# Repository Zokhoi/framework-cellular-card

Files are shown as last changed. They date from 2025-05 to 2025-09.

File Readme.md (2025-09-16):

## Framework Cellular Expansion Card

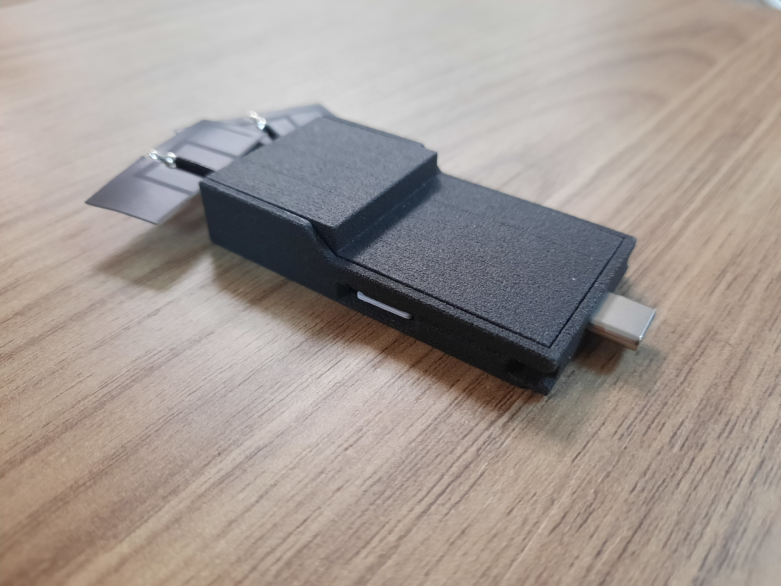
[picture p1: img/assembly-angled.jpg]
assembly-angled


Compatible with Quectel cellular modules with same pinout as BG96.

This PCB design has been tested with EG912U-GL and EG95-EX modules. Other modules with compatible pinout will need different component values in various positions, consult the relevant hardware design information for details.

This PCB design is in alpha state, therefore gerber will not be provided and you should only proceed ordering at your own risk.

This PCB design does not incorporate built in antennas, and instead includes MHF-1 connectors for LTE main, diversity and GNSS. Thus you should pair your own 50 ohms impedance LTE antenna.

The PCB is 15mm longer than a regular expansion card PCB, a preliminary case design is provided.

### Board specifications

Size 26mm x 45mm, thickness 0.8mm, 4 layers, copper thickness 1oz 0.5oz 0.5oz 1oz, impedance controlled board with 0.2mm prepreg

### Compatible modem series comparison

| Modem series | Cellular standards | Downlink speed | Uplink speed | Cost |
|---|---|---|---|---|
| EG95 | 4G, 3G, 2G | 150 Mb/s |  50 Mb/s | \$\$ |
| EG91 | 4G, 2G |  10 Mb/s | 5 Mb/s | \$ |
| BG96 | Cat-M, Cat-NB1 | 375 Kb/s | 375 Kb/s | \$\$ |

### License
This hardware design is licensed under [CERN-OHL-W V2 or later](License.txt).

### Board preview
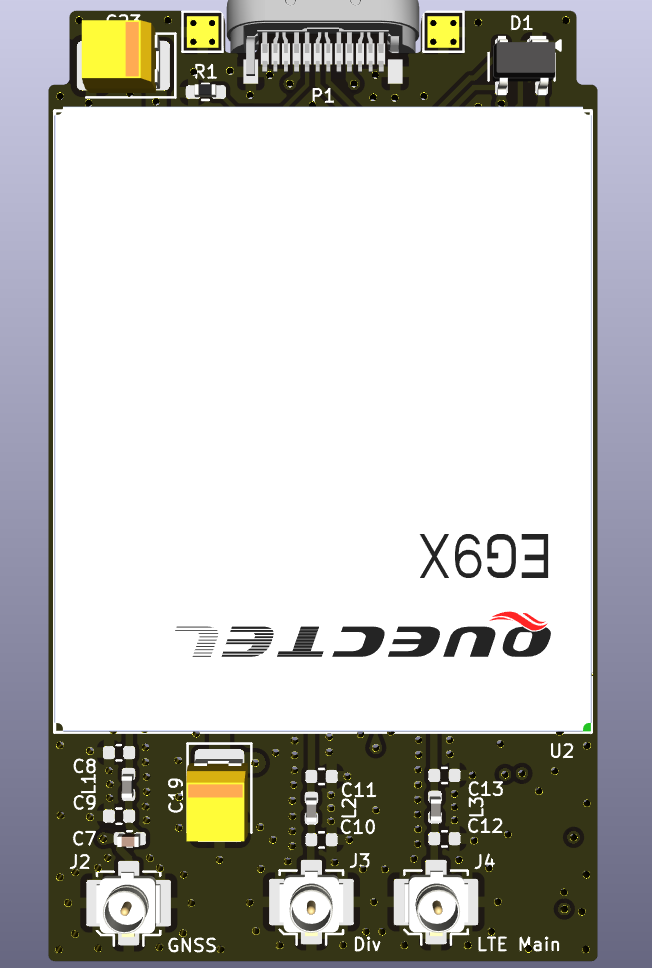
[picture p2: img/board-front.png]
front


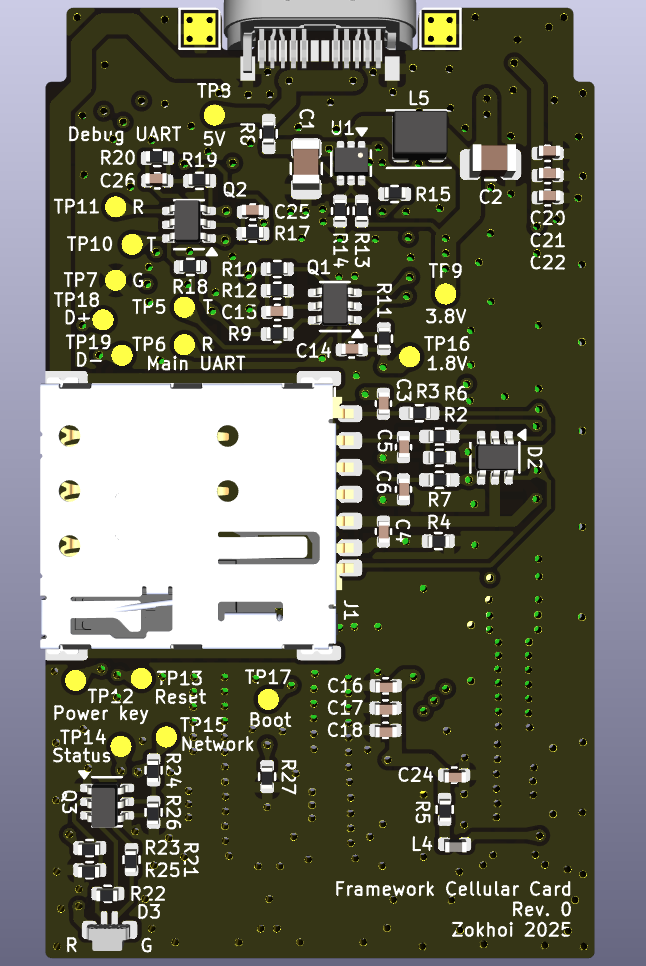
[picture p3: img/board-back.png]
back


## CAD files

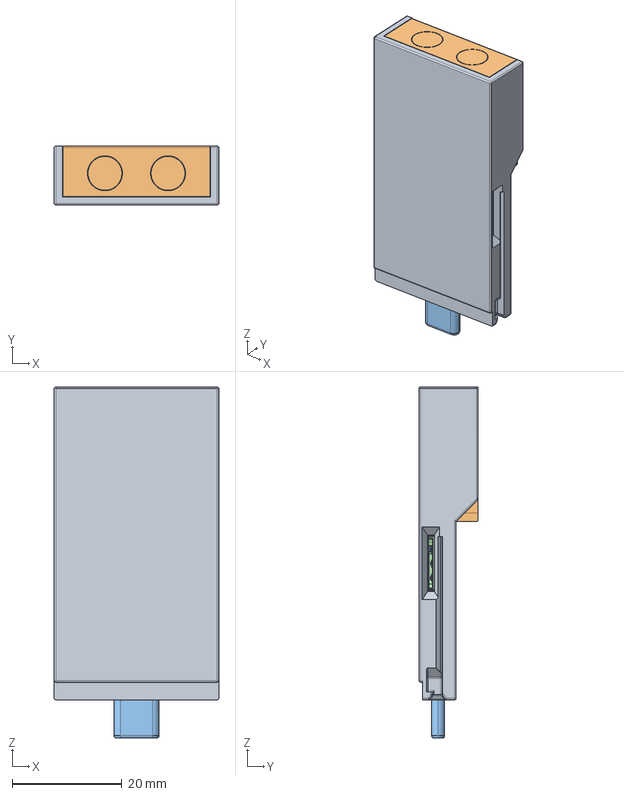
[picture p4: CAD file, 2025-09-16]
case/usb-lte-case.FCStd
30.0 x 10.8 x 64.0 mm
Bottom shell
Top shell
C_0402_1005Metric
C_0402_1005Metric002
U.FL_Hirose_U.FL-R-SMT-1_Vertical
C_0402_1005Metric004
C_0402_1005Metric006
C_0402_1005Metric008
C_0402_1005Metric010
C_0402_1005Metric012
L_0402_1005Metric
L_0402_1005Metric002
U.FL_Hirose_U.FL-R-SMT-1_Vertical002
L_0402_1005Metric004
R_0402_1005Metric
CP_EIA_3528_21_Kemet_B
CP_EIA_3528_21_Kemet_B001
SOT_143
U.FL_Hirose_U.FL-R-SMT-1_Vertical004
EG91
EG092
EG093
EG094
EG095
EG096
EG097
EG098
EG099
EG100
EG101
EG102
EG103
EG104
EG105
EG106
EG107
EG108
EG109
EG110
EG111
EG112
EG113
EG114
EG115
EG116
EG117
EG118
EG119
EG120
EG121
EG122
EG123
EG124
EG125
EG126
EG127
EG128
EG129
EG130
EG131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

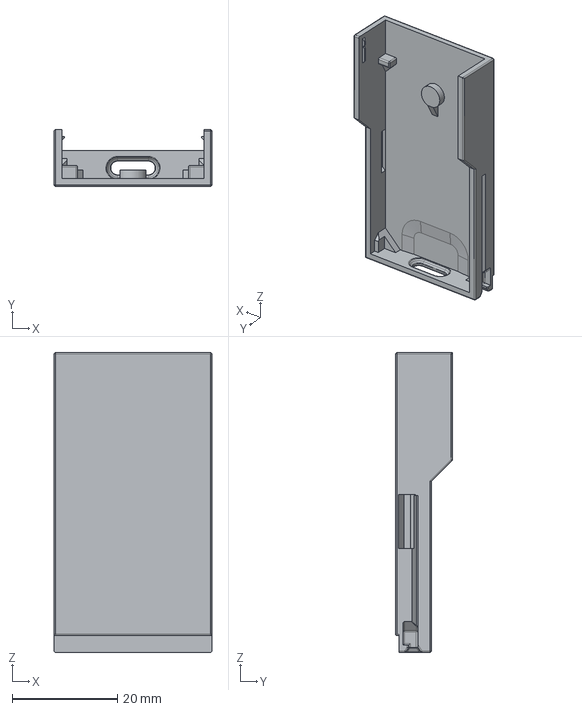
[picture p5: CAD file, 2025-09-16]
case/v1/usb-lte-case-Bottom shell.step
30.0 x 10.8 x 57.0 mm

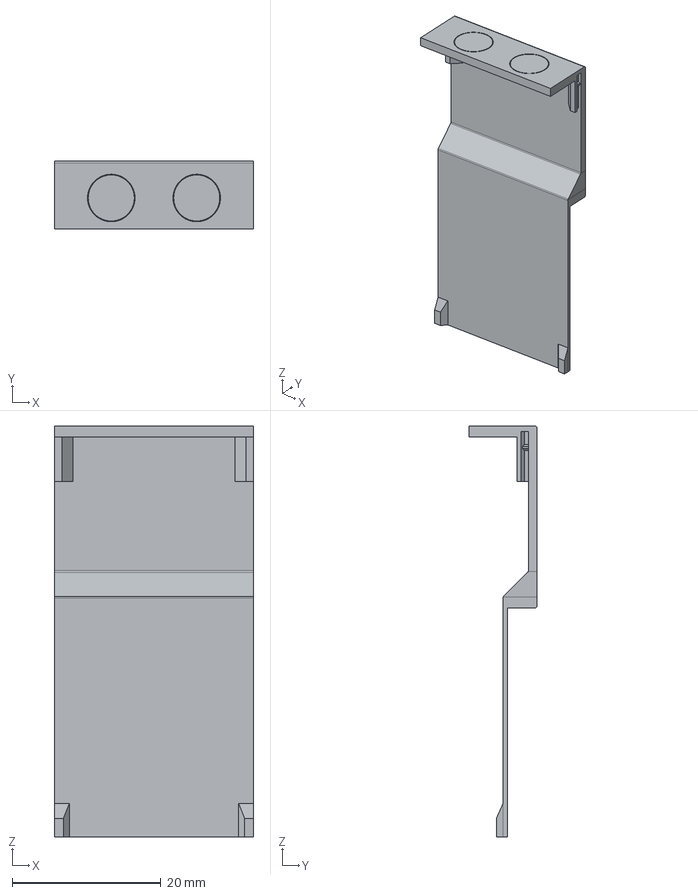
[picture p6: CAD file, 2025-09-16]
case/v1/usb-lte-case-Top shell.step
26.8 x 9.20 x 55.3 mm

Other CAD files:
case/v1/usb-lte-case-Bottom shell.3mf
case/v1/usb-lte-case-Top shell.3mf

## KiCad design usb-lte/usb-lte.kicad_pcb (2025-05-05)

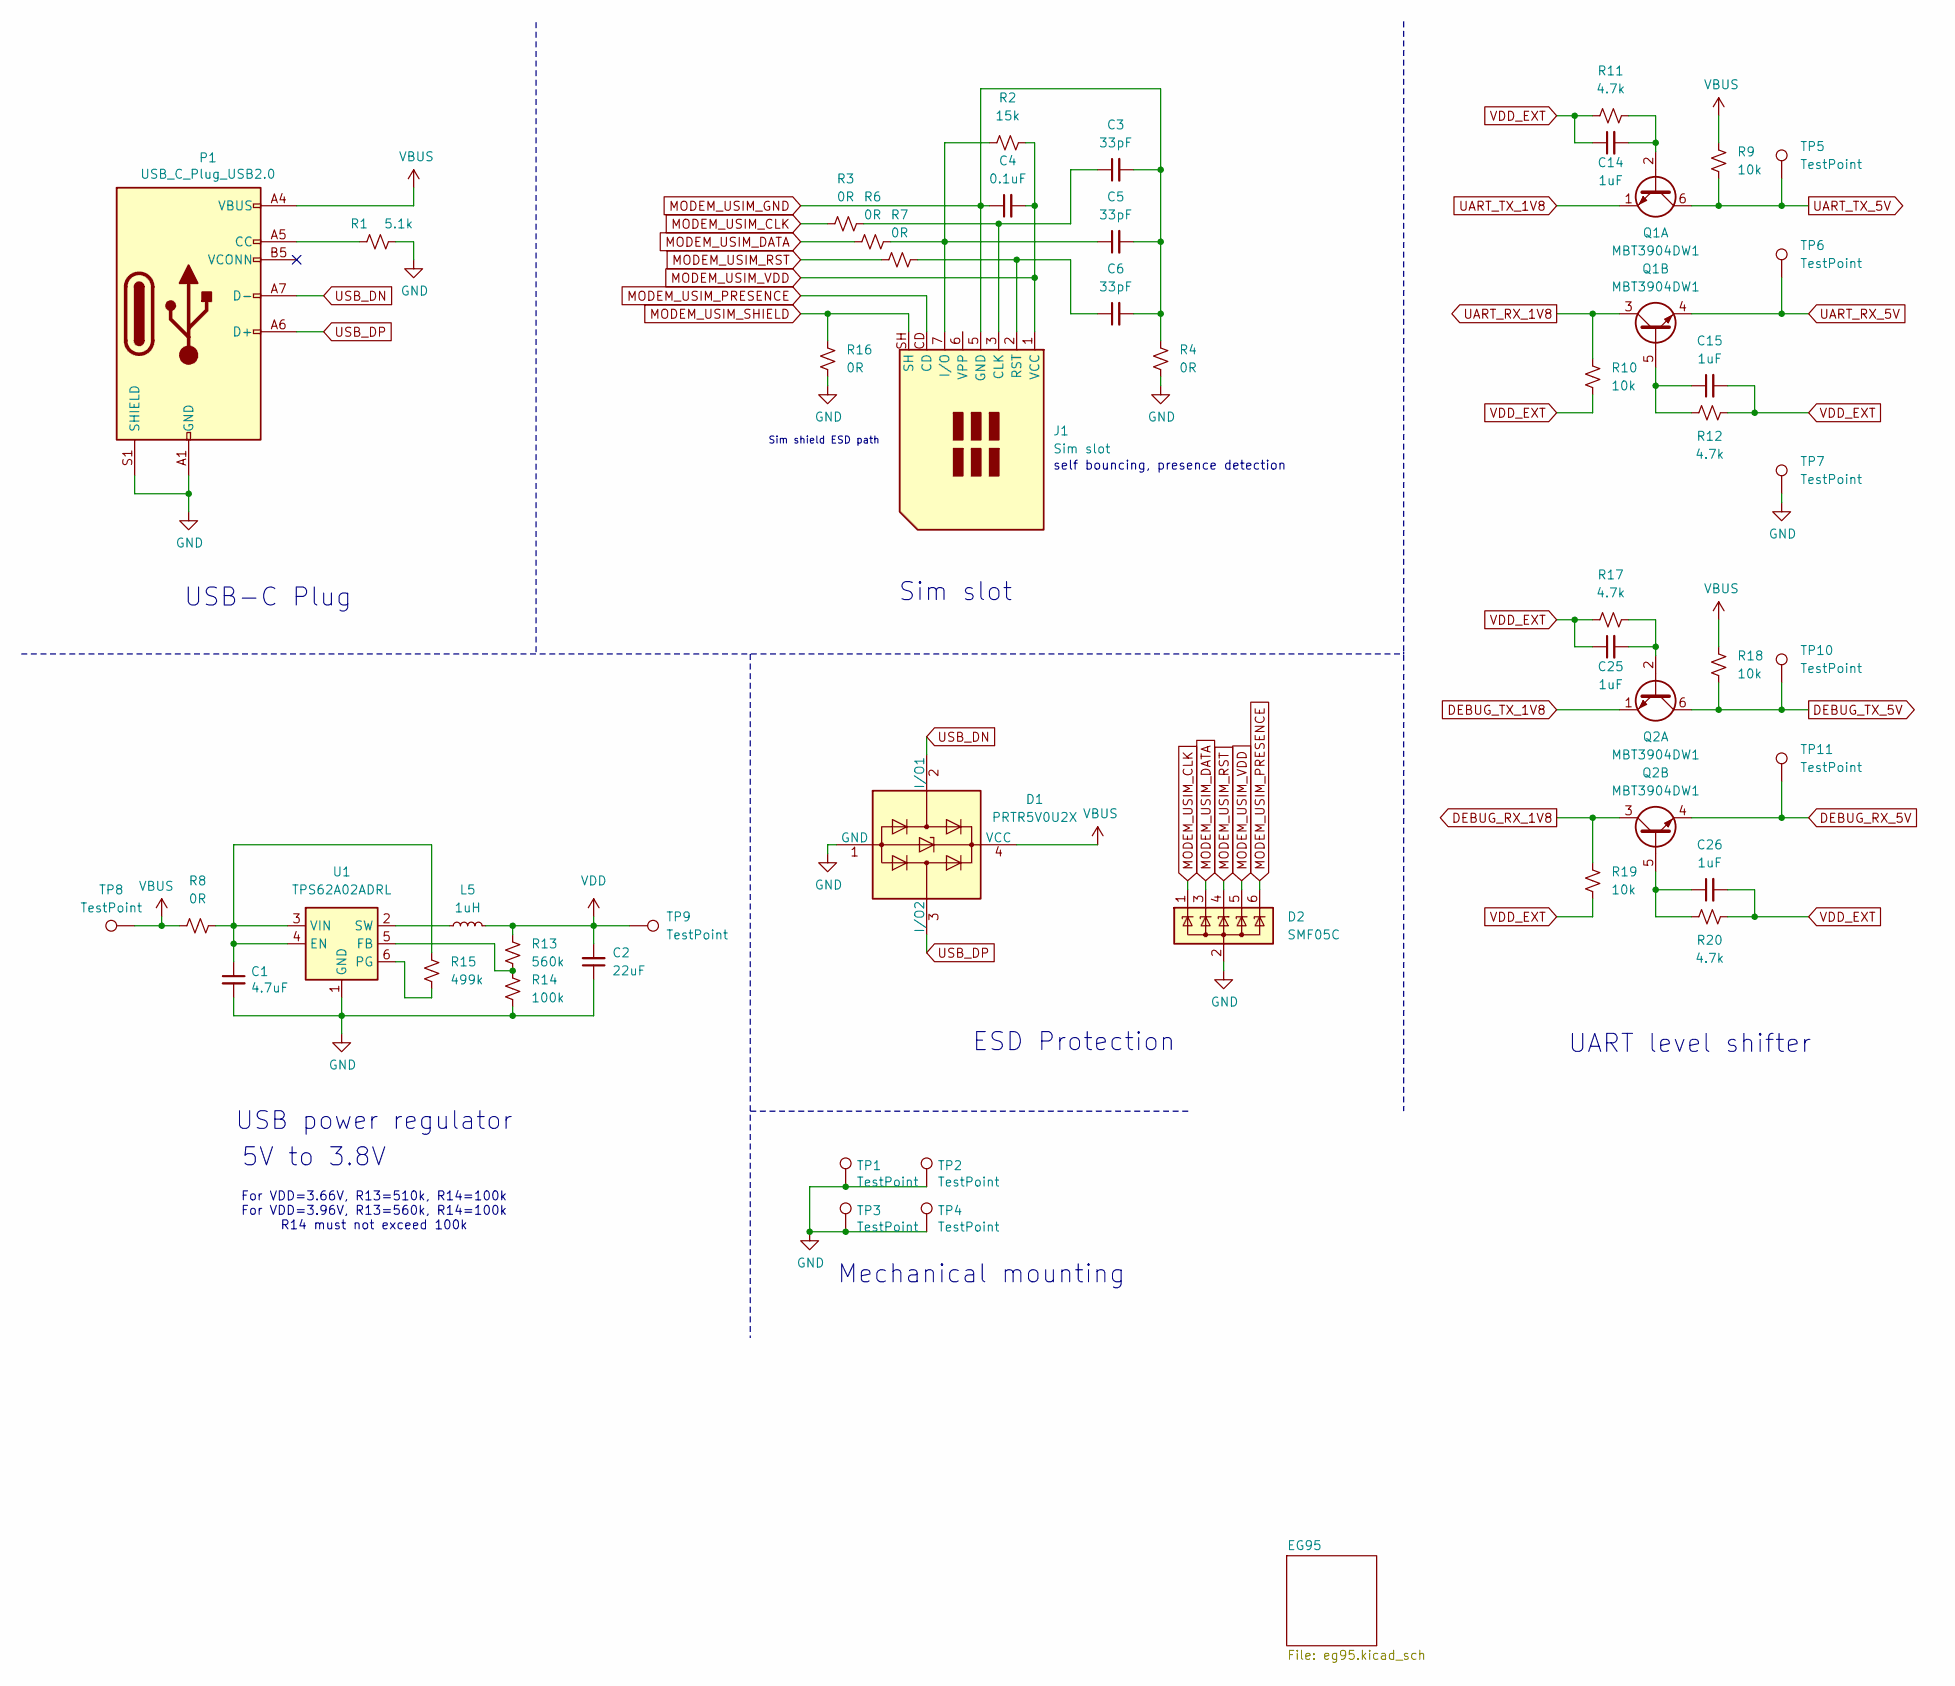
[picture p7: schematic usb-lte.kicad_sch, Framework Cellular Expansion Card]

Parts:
C1: 4.7uF; C_0805_2012Metric
C2: 22uF; C_0805_2012Metric
C3, C5, C6: 33pF; C_0402_1005Metric
C4: 0.1uF; C_0402_1005Metric
C14, C15, C25, C26: 1uF; C_0402_1005Metric
D1: PRTR5V0U2X; SOT-143
D2: SMF05C; SOT-363_SC-70-6
J1: Sim slot; SIM_Card_Self_Bounce_Detection
L5: 1uH; L_APV_ANR252012
P1: USB_C_Plug_USB2.0; USB_C_Plug_Molex_105444
Q1, Q2: MBT3904DW1; SOT-363_SC-70-6
R1: 5.1k; R_0402_1005Metric_Pad0.72x0.64mm_HandSolder
R2: 15k; R_0402_1005Metric
R3, R6, R7, R8: 0R; R_0402_1005Metric_Pad0.72x0.64mm_HandSolder
R4: 0R; R_0402_1005Metric
R9, R10, R18, R19: 10k; R_0402_1005Metric
R11, R12, R17, R20: 4.7k; R_0402_1005Metric
R13: 560k; R_0402_1005Metric
R14: 100k; R_0402_1005Metric
R15: 499k; R_0402_1005Metric
R16: 0R; ESD shunt
TP1, TP2, TP3, TP4: TestPoint; TestPoint_Pad_1.5x1.5mm
TP5, TP6, TP7, TP8, TP9, TP10, TP11: TestPoint; TestPoint_Pad_1mm
U1: TPS62A02ADRL; SOT-563

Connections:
DEBUG_RX_1V8: Q2.3 (C2), R19.1; also elsewhere on the board
DEBUG_RX_5V: Q2.4 (E2), TP11.1
DEBUG_TX_1V8: Q2.1 (E1); also elsewhere on the board
DEBUG_TX_5V: Q2.6 (C1), R18.2, TP10.1
GND: C1.2, C2.1, D1.1 (GND), D2.2 (A), P1.A1 (GND), P1.A12 (GND), P1.B1 (GND), P1.B12 (GND), P1.S1 (SHIELD), R1.2, R4.2, R14.2, R16.2, TP1.1, TP2.1, TP3.1, TP4.1, TP7.1, U1.1 (GND); also elsewhere on the board
MODEM_USIM_CLK: D2.1 (K), R3.1; also elsewhere on the board
MODEM_USIM_DATA: D2.3 (K), R6.1; also elsewhere on the board
MODEM_USIM_GND: C3.2, C4.1, C5.2, C6.2, J1.5 (GND), R4.1; also elsewhere on the board
MODEM_USIM_PRESENCE: D2.6 (K), J1.CD; also elsewhere on the board
MODEM_USIM_RST: D2.4 (K), R7.1; also elsewhere on the board
MODEM_USIM_SHIELD: J1.SH, R16.1
MODEM_USIM_VDD: C4.2, D2.5 (K), J1.1 (VCC), R2.2; also elsewhere on the board
unnamed: C3.1, J1.3 (CLK), R3.2
unnamed: C5.1, J1.7 (I/O), R2.1, R6.2
unnamed: C6.1, J1.2 (RST), R7.2
unnamed: P1.A5 (CC), R1.1
unnamed: C14.2, Q1.2 (B1), R11.2
unnamed: C15.1, Q1.5 (B2), R12.1
unnamed: C25.2, Q2.2 (B1), R17.2
unnamed: C26.1, Q2.5 (B2), R20.1
unnamed: C1.1, R8.2, R15.2, U1.3 (VIN), U1.4 (EN)
unnamed: R13.2, R14.1, U1.5 (FB)
unnamed: R15.1, U1.6 (PG)
unnamed: L5.1, U1.2 (SW)
UART_RX_1V8: Q1.3 (C2), R10.1; also elsewhere on the board
UART_RX_5V: Q1.4 (E2), TP6.1
UART_TX_1V8: Q1.1 (E1); also elsewhere on the board
UART_TX_5V: Q1.6 (C1), R9.2, TP5.1
USB_DN: D1.2 (I/O1), P1.A7 (D-); also elsewhere on the board
USB_DP: D1.3 (I/O2), P1.A6 (D+); also elsewhere on the board
VBUS: D1.4 (VCC), P1.A4 (VBUS), P1.A9 (VBUS), P1.B4 (VBUS), P1.B9 (VBUS), R8.1, R9.1, R18.1, TP8.1; also elsewhere on the board
VDD: C2.2, L5.2, R13.1, TP9.1; also elsewhere on the board
VDD_EXT: C14.1, C15.2, C25.1, C26.2, R10.2, R11.1, R12.2, R17.1, R19.2, R20.2; also elsewhere on the board

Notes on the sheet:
Sim slot
USB power regulator
For VDD=3.66V, R13=510k, R14=100k For VDD=3.96V, R13=560k, R14=100k R14 must not exceed 100k
Mechanical mounting
self bouncing, presence detection
USB-C Plug
Sim shield ESD path
ESD Protection
UART level shifter
5V to 3.8V

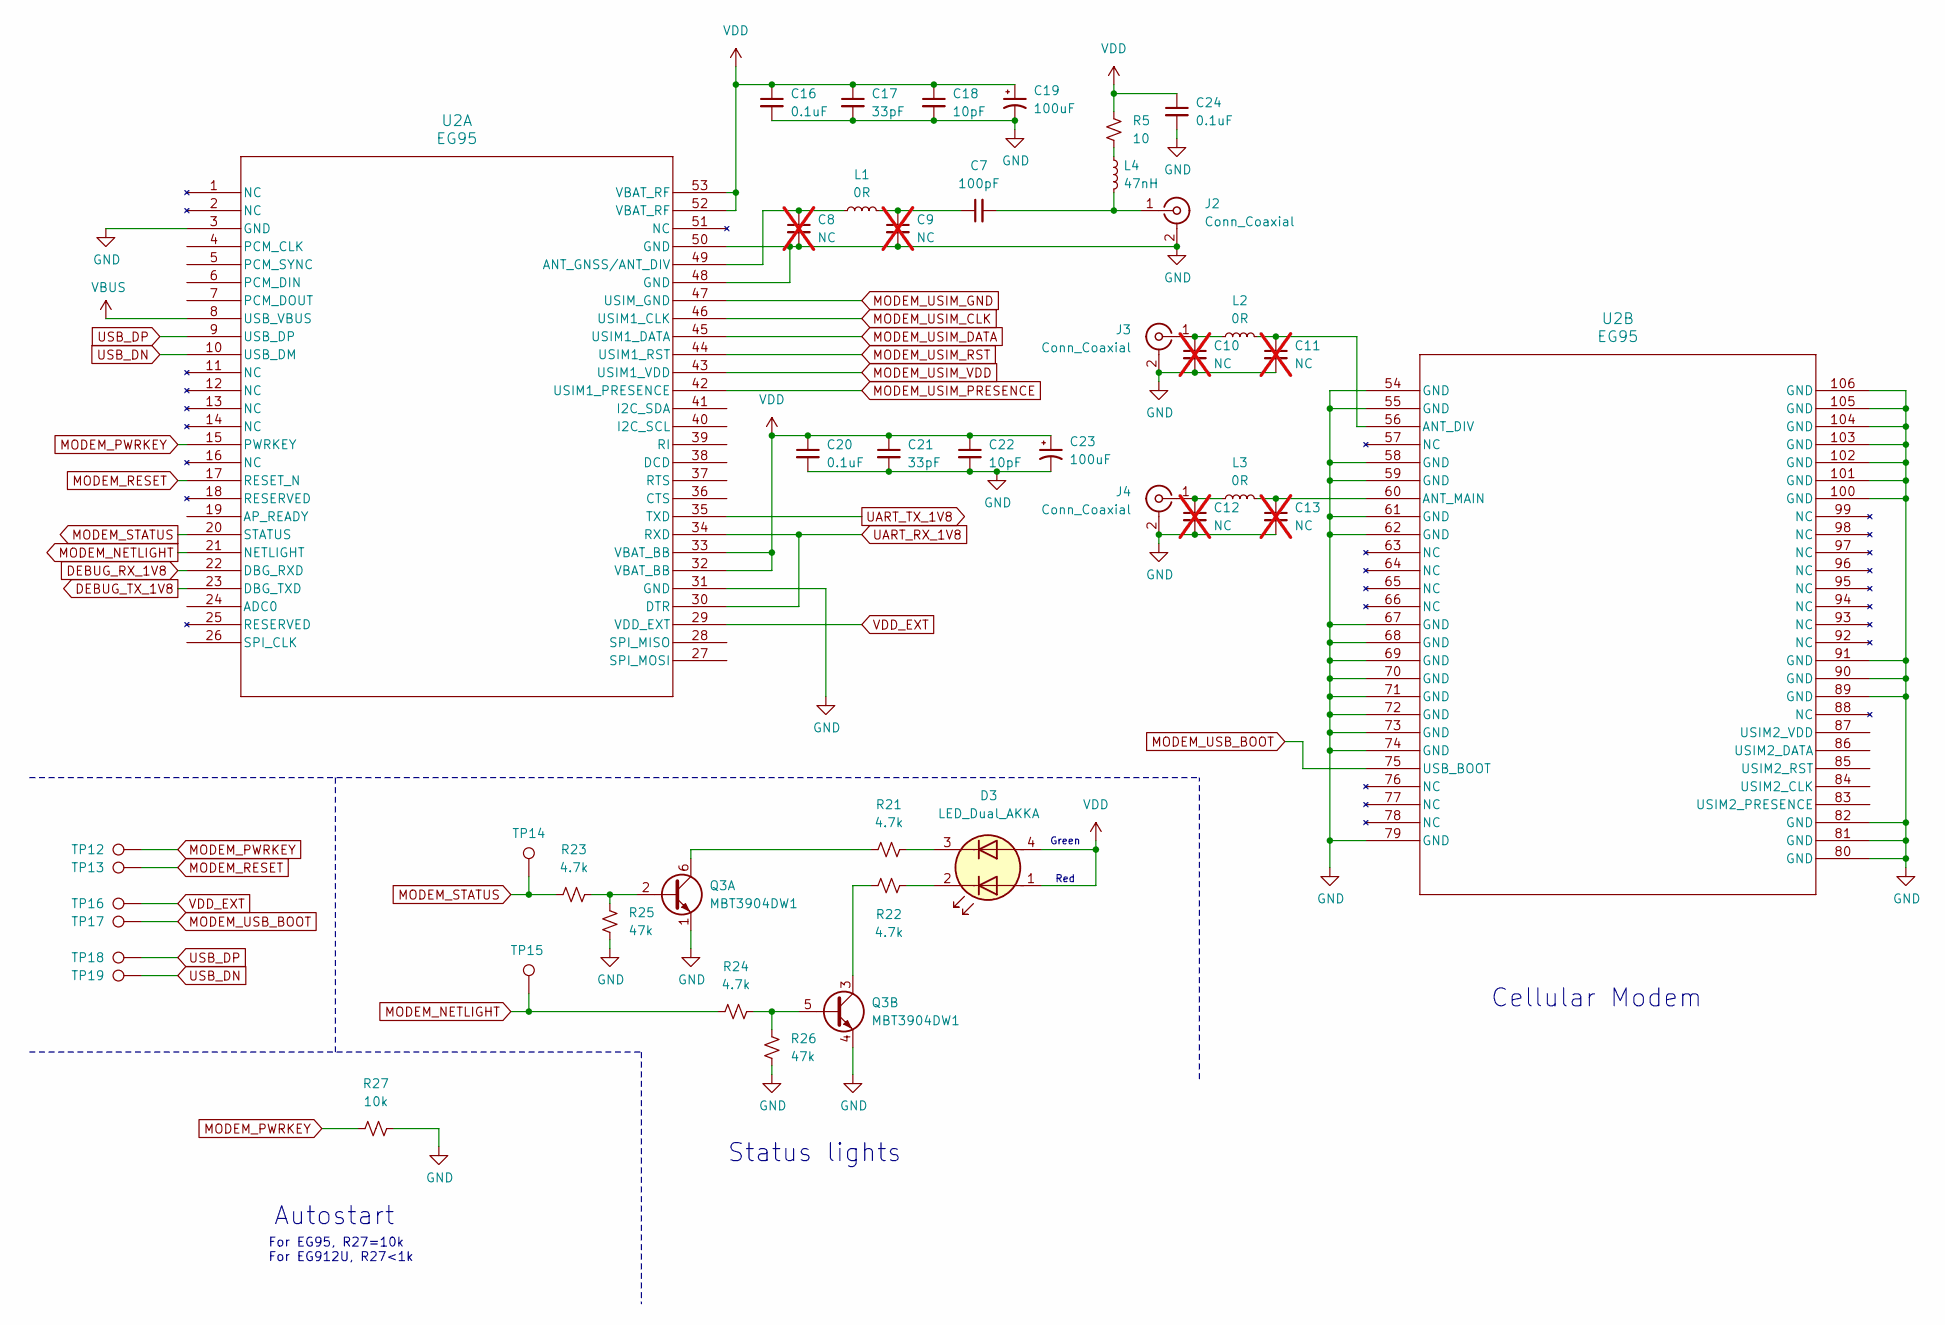
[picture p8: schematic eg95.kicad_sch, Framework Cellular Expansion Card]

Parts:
C7: 100pF; C_0402_1005Metric
C8, C9, C10, C11, C12, C13: NC; C_0402_1005Metric; not fitted
C16, C20, C24: 0.1uF; C_0402_1005Metric
C17, C21: 33pF; C_0402_1005Metric
C18, C22: 10pF; C_0402_1005Metric
C19, C23: 100uF; CP_EIA-3528-21_Kemet-B
D3: LED_Dual_AKKA; LED_Dual_0805_4pin
J2, J3, J4: Conn_Coaxial; U.FL_Molex_MCRF_73412-0110_Vertical
L1, L2, L3: 0R; L_0402_1005Metric
L4: 47nH; L_0402_1005Metric
Q3: MBT3904DW1; SOT-363_SC-70-6
R5: 10; R_0402_1005Metric
R21, R22, R23, R24: 4.7k; R_0402_1005Metric
R25, R26: 47k; R_0402_1005Metric
R27: 10k; R_0402_1005Metric
TP12, TP13, TP14, TP15, TP16, TP17, TP18, TP19: TestPoint; TestPoint_Pad_1mm
U2: EG95; EG95_QWS

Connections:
DEBUG_RX_1V8: U2.22 (DBG_RXD); also elsewhere on the board
DEBUG_TX_1V8: U2.23 (DBG_TXD); also elsewhere on the board
GND: C8.2, C9.2, C10.2, C11.2, C12.2, C13.2, C16.2, C17.2, C18.2, C19.2, C20.2, C21.2, C22.2, C23.2, C24.2, J2.2 (Ext), J3.2 (Ext), J4.2 (Ext), Q3.1 (E1), Q3.4 (E2), R25.1, R26.1, R27.1, U2.3 (GND), U2.31 (GND), U2.48 (GND), U2.50 (GND), U2.54 (GND), U2.55 (GND), U2.58 (GND), U2.59 (GND), U2.61 (GND), U2.62 (GND), U2.67 (GND), U2.68 (GND), U2.69 (GND), U2.70 (GND), U2.71 (GND), U2.72 (GND), U2.73 (GND), U2.74 (GND), U2.79 (GND), U2.80 (GND), U2.81 (GND), U2.82 (GND), U2.89 (GND), U2.90 (GND), U2.91 (GND), U2.100 (GND), U2.101 (GND), U2.102 (GND), U2.103 (GND), U2.104 (GND), U2.105 (GND), U2.106 (GND); also elsewhere on the board
MODEM_NETLIGHT: R24.2, TP15.1, U2.21 (NETLIGHT)
MODEM_PWRKEY: R27.2, TP12.1, U2.15 (PWRKEY)
MODEM_RESET: TP13.1, U2.17 (RESET_N)
MODEM_STATUS: R23.2, TP14.1, U2.20 (STATUS)
MODEM_USB_BOOT: TP17.1, U2.75 (USB_BOOT)
MODEM_USIM_CLK: U2.46 (USIM1_CLK); also elsewhere on the board
MODEM_USIM_DATA: U2.45 (USIM1_DATA); also elsewhere on the board
MODEM_USIM_GND: U2.47 (USIM_GND); also elsewhere on the board
MODEM_USIM_PRESENCE: U2.42 (USIM1_PRESENCE); also elsewhere on the board
MODEM_USIM_RST: U2.44 (USIM1_RST); also elsewhere on the board
MODEM_USIM_VDD: U2.43 (USIM1_VDD); also elsewhere on the board
unnamed: C7.1, C9.1, L1.2
unnamed: D3.2 (K1), R22.1
unnamed: D3.3 (K2), R21.1
unnamed: C7.2, J2.1 (In), L4.2
unnamed: C10.1, J3.1 (In), L2.1
unnamed: C12.1, J4.1 (In), L3.1
unnamed: L4.1, R5.1
unnamed: Q3.2 (B1), R23.1, R25.2
unnamed: Q3.6 (C1), R21.2
unnamed: Q3.5 (B2), R24.1, R26.2
unnamed: Q3.3 (C2), R22.2
unnamed: C8.1, L1.1, U2.49 (ANT_GNSS/ANT_DIV)
unnamed: C11.1, L2.2, U2.56 (ANT_DIV)
unnamed: C13.1, L3.2, U2.60 (ANT_MAIN)
UART_RX_1V8: U2.30 (DTR), U2.34 (RXD); also elsewhere on the board
UART_TX_1V8: U2.35 (TXD); also elsewhere on the board
USB_DN: TP19.1, U2.10 (USB_DM); also elsewhere on the board
USB_DP: TP18.1, U2.9 (USB_DP); also elsewhere on the board
VBUS: U2.8 (USB_VBUS); also elsewhere on the board
VDD: C16.1, C17.1, C18.1, C19.1, C20.1, C21.1, C22.1, C23.1, C24.1, D3.1 (A1), D3.4 (A2), R5.2, U2.32 (VBAT_BB), U2.33 (VBAT_BB), U2.52 (VBAT_RF), U2.53 (VBAT_RF); also elsewhere on the board
VDD_EXT: TP16.1, U2.29 (VDD_EXT); also elsewhere on the board

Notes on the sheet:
Green
Cellular Modem
Autostart
For EG95, R27=10k For EG912U, R27<1k
Red
Status lights

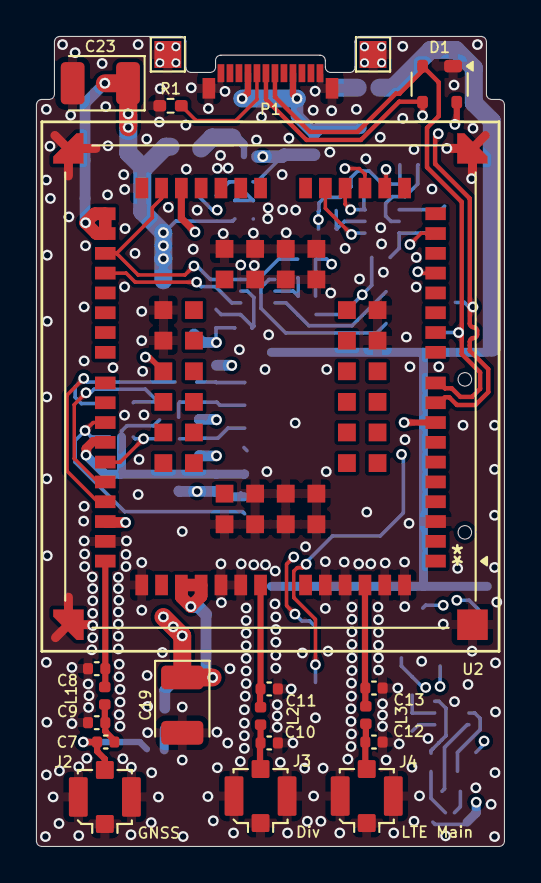
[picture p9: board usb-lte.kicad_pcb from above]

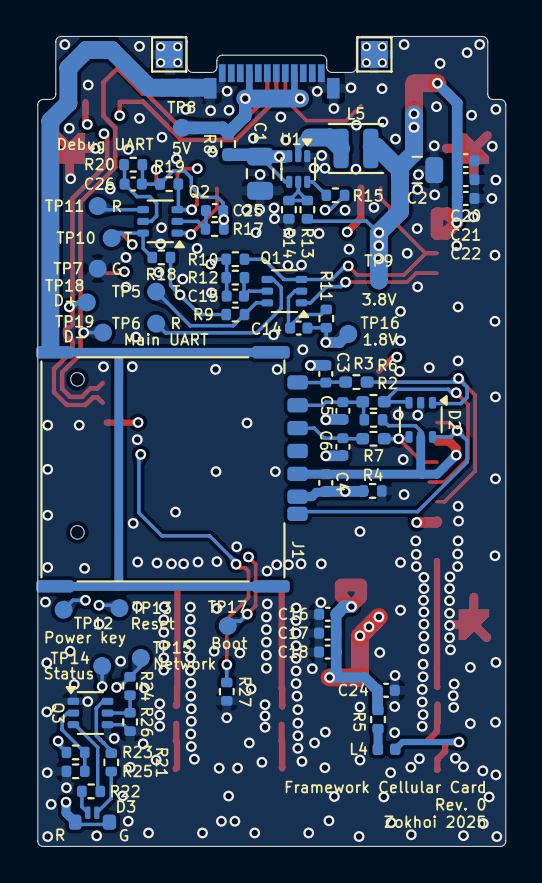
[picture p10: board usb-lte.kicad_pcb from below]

Board: 4 copper layers, 26.0 x 45.0 mm, 90 parts (69 on the bottom side), 52 nets.

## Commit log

2025-03-26 Mark pi network caps as NC
    [eg95.kicad_sch, usb-lte.kicad_pcb]
2025-03-26 separate gnd and sim gnd
    [usb-lte.kicad_pcb, usb-lte.kicad_sch]
2025-03-27 added positioning NPTH for sim slot
    [usb-lte.kicad_pcb]
2025-03-28 match usb 90 ohm impedance
    [usb-lte.kicad_pcb]
2025-03-30 Use main power rail for gnss antenna
    [eg95.kicad_sch, usb-lte.kicad_pcb]
2025-04-05 Use SMPS and 3.8V for module
    [eg95.kicad_sch, usb-lte.kicad_pcb, usb-lte.kicad_sch]
2025-04-05 Make USB C 2.0 reversible
    [usb-lte.kicad_pcb, usb-lte.kicad_sch]
2025-04-05 Minor changes
    [usb-lte.kicad_pcb, usb-lte.kicad_sch]
2025-04-05 Add TVS diode for sim slot
    [usb-lte.kicad_pcb, usb-lte.kicad_sch]
2025-04-06 Moved TVS diode closer to sim slot
    [usb-lte.kicad_pcb, usb-lte.kicad_sch]
2025-04-09 Add debug uart breakout
    [usb-lte.kicad_pcb, usb-lte.kicad_sch]
2025-04-09 Add various test points
    [eg95.kicad_sch, usb-lte.kicad_pcb]
2025-04-19 Add status lights and usb boot key
    [usb-lte.kicad_pcb, usb-lte.kicad_sch]
2025-04-21 Update 3d models
    [eg95.kicad_sch, usb-lte.kicad_pcb]
2025-04-21 Update test points
    [eg95.kicad_sch, usb-lte.kicad_pcb, usb-lte.kicad_sch]
2025-05-04 Remove USB boot key, add autostart pull down
    [eg95.kicad_sch, usb-lte.kicad_pcb]
2025-05-05 Fix SMPS chip variant number
    [usb-lte.kicad_pcb, usb-lte.kicad_sch]
2025-09-16 Add case design
    [usb-lte-case-Bottom shell.3mf, usb-lte-case-Bottom shell.step, usb-lte-case-Top shell.3mf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]
2026-10-30 Add chip antenna version
2026-11-01 Add chip antenna version R2
    This uses Quectel YC0017EA chip antenna.
2026-11-01 Fix antenna pin 1 marking
